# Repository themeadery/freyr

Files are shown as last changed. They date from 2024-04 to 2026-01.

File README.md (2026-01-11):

# Freyr

NOTE: This documentation is horribly out of date. There is exactly ONE user of this software: me, so updating it hasn't been a priority. I keep making major changes and not documenting.

tl;dr Yeah, but what does it look like?

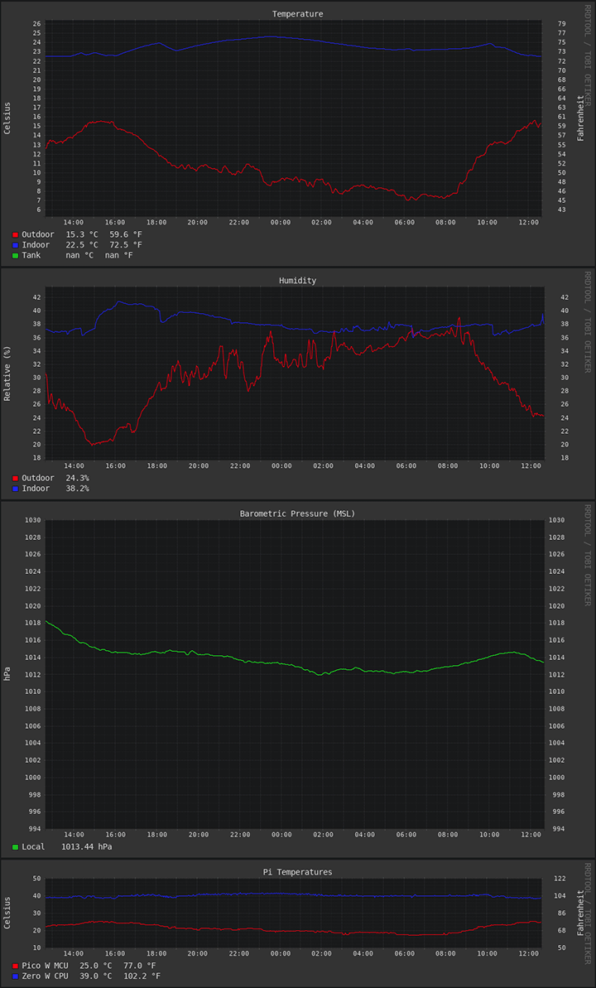
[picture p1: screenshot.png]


This started out as a project to control my reef aquarium, hence the name. It then morphed into a simple Python script to check the indoor temp/humidity and compare it with the outdoors using OpenWeather API. Update: It now monitors the temperature of my aquarium!

## Raspberry Pi

I moved the project from a FT232H to a Raspberry Pi Zero W and added a DS18B20 waterproof temperature sensor for an aquarium. With plenty of GPIO on the Pi and relays in hand, I plan on controlling pumps/lights/etc in the future.

### Hardware

#### BME680

<https://pinout.xyz/pinout/i2c>

- VCC to 3v3 (pin 1)
- GND to ground (any)
- SCL to GPIO 3 [I2C1 SCL Clock] (pin 5)
- SDA to GPIO 2 [I2C1 SDA Data] (pin 3)
- SDO to nothing
- CS to ground (any)

During testing I kept having failures of the sensor until I discovered an unofficial fix that contradicts the official documentation a bit. CS must be run to a ground pin. All of a sudden the sensor was rock solid stable for weeks after that.

#### Si7021

<https://pinout.xyz/pinout/i2c>

- VIN to 3v3 (pin 1)
- GND to ground (pin 9)
- SCL to GPIO 3 [I2C1 SCL Clock] (pin 5)
- SDA to GPIO 2 [I2C1 SDA Data] (pin 3)

This sensor always seems to work no matter what and is very accurate. I am impressed with the performance. I am currently using it outdoors on a Pico W, so the wiring is different than shown above.

#### DS18B20

<https://pinout.xyz/pinout/1_wire>

- Red Wire to 5v (pin 2)
- Blue Wire to ground (pin 6 or 9)
- Yellow Wire to GPIO 4 [Data] (pin 7)
- 4k7 pullup resistor between 5V and Data (yellow wire)

According to my testing, Google searches, and the DS18B20 datasheet 3v3 is not enough voltage to pull up the data line with the commonly included 4k7 resistor. I measured ~1.6 volts with the 4k7 resistor in place and the datasheet says it wants a minimum of 3.0 volts. I was having massive dropouts of the sensor until I switched everything from the 3v3 rail to the 5v rail. I don't know how anybody else got it working on 3v3 and then wrote the guides floating around the web (I'm looking at you too Adafruit!). You could, of course, substitute an appropriate resistor and still use 3v3 based on some multimeter measuring, calculating, etc. But why not give that sucker some juice! It's been rock solid since I changed to the 5v rail + 4k7 pullup.

### Dependencies

You can satisfy pretty much all dependencies with these commands on a fresh Pi:

```bash
sudo apt install git nginx rrdtool python3-rrdtool python3-pip
sudo pip install adafruit-circuitpython-si7021
sudo pip install git+https://github.com/nicmcd/vcgencmd.git
```

I2C and 1-Wire interfaces must be turned on in ```$ sudo raspi-config```

### RRD

#### Create RRD databases

```bash
rrdtool create temperatures.rrd --step 60 DS:outdoor:GAUGE:120:-20:55 DS:indoor:GAUGE:120:0:55 DS:tank:GAUGE:120:0:55 DS:pi:GAUGE:120:0:100 DS:picow:GAUGE:120:0:100 DS:outdoor_dew:GAUGE:120:-80:55 DS:indoor_dew:GAUGE:120:-80:55 RRA:LAST:0.5:1:2880
rrdtool create humidities.rrd --step 60 DS:outdoor:GAUGE:120:0:100 DS:indoor:GAUGE:120:0:100 RRA:LAST:0.5:1:2880
rrdtool create pressures.rrd --step 60 DS:indoor:GAUGE:120:900:1100 RRA:LAST:0.5:1:2880
rrdtool create gas.rrd --step 60 DS:indoor:GAUGE:120:50:200000 RRA:LAST:0.5:1:2880
rrdtool create uv.rrd --step 60 DS:outdoor:GAUGE:120:0:20 RRA:LAST:0.5:1:2880
rrdtool create wind.rrd --step 60 DS:outdoor_wind:GAUGE:120:0:100 DS:outdoor_windGust:GAUGE:120:0:100 RRA:LAST:0.5:1:2880
```

This will create databases with a 60 second interval, 120 second heartbeat timeout, between -20 and 55 degrees Celsius for the outdoor sensor, between 0 and 55 degrees Celsius for the indoor sensors, between -80 and 55 degrees Celsius dewpoints, 0-100 degrees Celsius for the pi CPU sensor, 0-100% relative humidity, 800-1100 hPa pressure, and 50-200,000 ohms gas resistance with 48 hours of data before rolling over. The uv database will have an 1800 second interval with a 3600 second heartbeat timeout (due to API rate limits at openuv.io) and a range between 0-20 (unitless). The wind database will have a 120 second interval with a 240 second heartbeat timeout (due again to API rate limits at OWM) and a range between 0-100 mph.

More information here: <https://michael.bouvy.net/post/graph-data-rrdtool-sensors-arduino>

### HTML

```index.html```

Very simple HTML to display the graphs. You will likely want a webserver for this. I use nginx. It refreshes the page every 30 seconds in an attempt to reduce misses while the graphs are being generated. This doesn't work very well, so I would love to implement a server-side generated trigger for refresh, more like a "push" based system. Unfortunately, when I first looked into implementing this it looked way too complicated for my motivation at the time. Looking for better solutions.

### Relay

There are 3 python files to control a relay on the Pi GPIO pins. You can use this as a timer for lights, pumps, etc.

```relayOn.py``` Simply turns on the relay

```relayOff.py``` Simply turns off the relay

```relay.py``` Toggles the relay based on a schedule

I used ```relay.py``` for a while, but there's no need to have a constantly running python daemon just to flip a GPIO pin twice a day. I switched to a crontab schedule using the first two mentioned python scripts.

Use the example below to turn a light on at 7:00 AM and off at 7:00 PM:

```bash
crontab -e
```

```text
# m h  dom mon dow   command
0 7 * * * python /home/pi/relayOn.py
0 19 * * * python /home/pi/relayOff.py
```

### More Advanced Relay Control

```bash
pip install flask
python relayControl.py
```

This will launch a webserver that hosts a very simple webpage with some buttons that control a relay. This depends on relayOn.py and relayOff.py, which you can edit to your liking and of course expand everything to control more relays.

### Handling Unforseen Errors

I have tried to continually improve error handling inside the main ```reefer.py``` script, however there are still errors that can pop up. I am usually running the script using ```$ python reefer.py &``` or some variation thereof to background the process and/or handle stdout/stderr logging (in addition to the built-in logging), but I am still getting various crashes which are not obvious looking at the graphs (they just stop on the last data point). So there is no way of knowing the main process crashed besides waiting a while and seeing the timestamp at the extreme right of the graphs is old.

The API's I am poking prove to be a continuous source of beard-pulling as I try to debug what is failing. I honestly did not expect polling of aviation METAR data from a government website to be so unreliable for example.

systemd to the rescue?

```bash
mkdir -p .config/systemd/user
cp reefer.service .config/systemd/user
systemctl --user start reefer
systemctl --user enable reefer
sudo loginctl enable-linger pi
```

This should automatically restart the script if it fails in any fashion and also log it properly. Note that this service is running as the unprivileged 'pi' user. The way I have my files setup in the pi home dir and nginx makes this work for my particular setup. You could do this all as root in ```/etc/systemd/system``` if you want to do it that way and manage permissions accordingly.

The ```reefer.service``` systemd unit file is very simple and included in the repo:

```text
[Unit]
Description=Reefer Service
After=network.target

[Service]
Type=simple
ExecStart=/usr/bin/python /home/pi/reefer.py
Restart=always

[Install]
WantedBy=multi-user.target
```

Note: The service file(s) have been updated to run as root like most services. No need to 'systemctl --user' anymore.

I realize this is turning more into a glorified weather station app, but that's where my interests have led me!

#### TODO

- ~~Move generated files to tmpfs as to not kill the sdcard with all the writes.~~
- Document tmpfs and symbolic link to files
- ~~Maybe switch from nginx to built-in Python webserver to further reduce system load, configuration, writes to sdcard, etc.~~
- Remove DS18B20 references and documentation
- Add BME680 documentation
- ~~Add Pi Pico W + Si7021 sattelite sensor code~~ and documentation
- ~~Squash indoor/outdoor pressures to "local"~~
- ~~Output data to Wunderground~~
- ~~Break out more things in main loop to functions and use main loop for flow control only (aka refactoring?)~~
- ~~Add High/Low stats~~
- ~~Log rotation using logging.handlers.RotatingFileHandler~~
- ~~Break out graphing args to variables, squash common args to reusable variable~~
- ~~Switch to built in Python module~~
- ~~Break secrets out to external file (lat, lon, API key, etc)~~
- ~~Fix readings from barometer and gas resistance sensor on first loop iteration~~
- ~~Rename project to Freyr~~

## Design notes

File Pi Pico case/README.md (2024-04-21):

"Case_Lower_No_Vent.stl" needs to be scaled to 10% to be the correct size

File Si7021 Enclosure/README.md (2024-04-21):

flip the Top part over 180° before printing

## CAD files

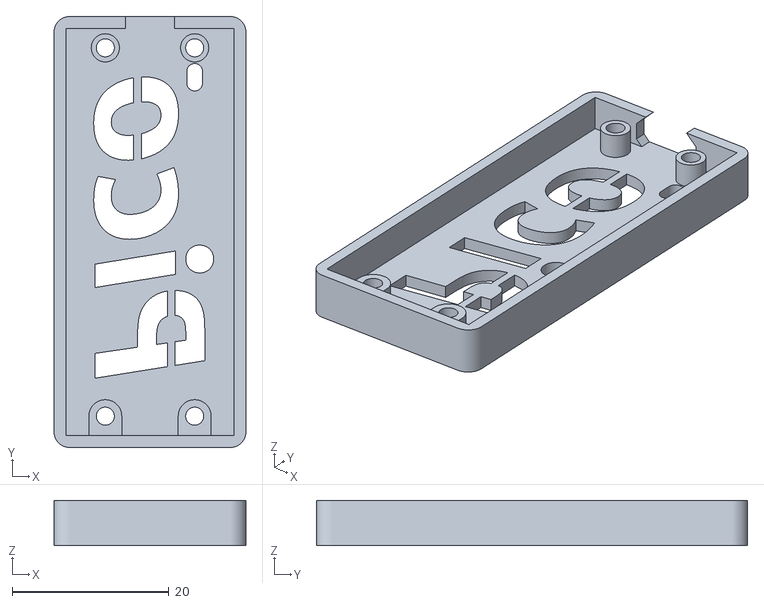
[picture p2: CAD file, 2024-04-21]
Pi Pico case/Case_Upper.STL
24.5 x 55.0 x 5.80

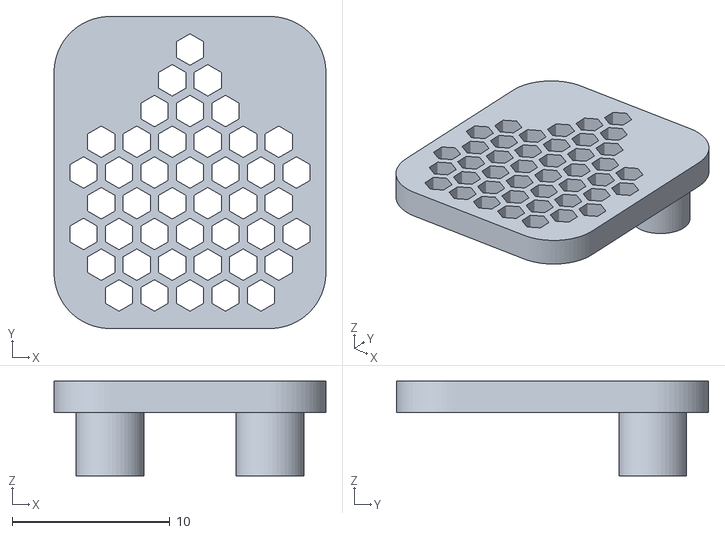
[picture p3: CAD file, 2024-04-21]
Si7021 Enclosure/Top.stl
17.2 x 19.8 x 6.00

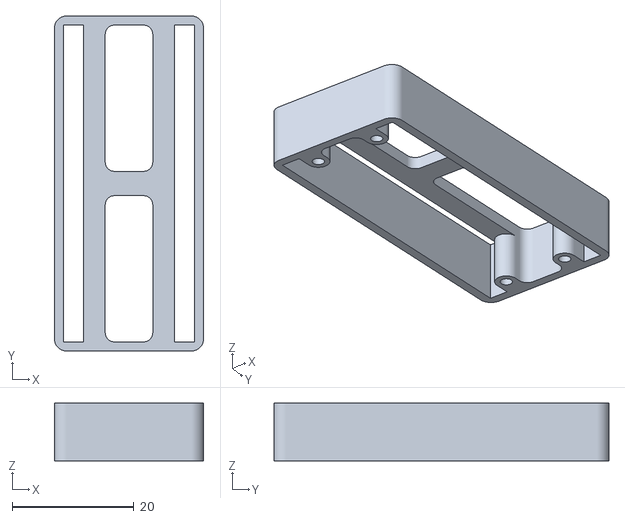
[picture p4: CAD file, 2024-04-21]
Pi Pico case/Case_Lower.STL
24.5 x 55.0 x 9.50

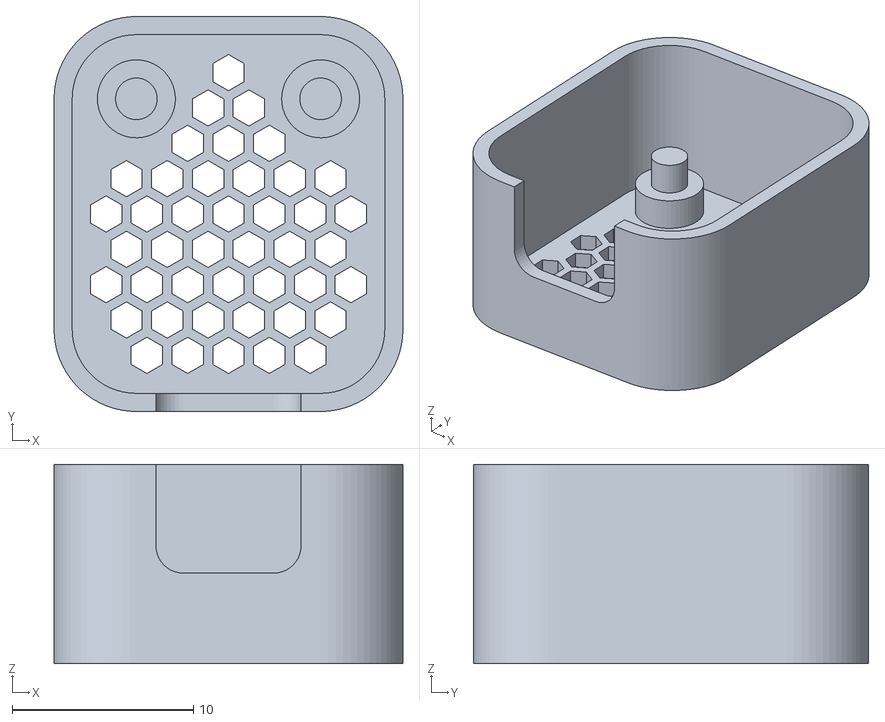
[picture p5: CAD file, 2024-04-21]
Si7021 Enclosure/Bottom.stl
19.2 x 21.8 x 11.0

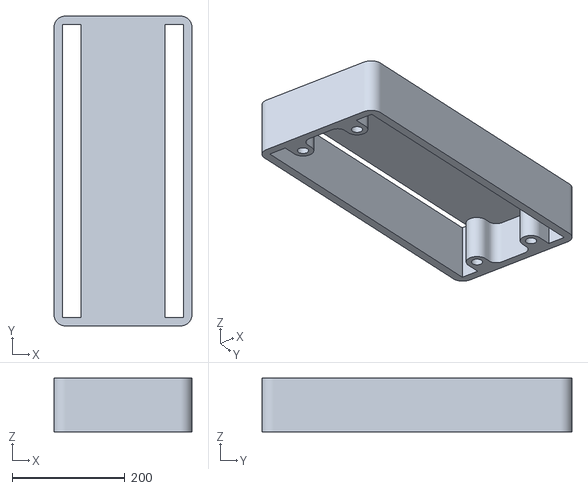
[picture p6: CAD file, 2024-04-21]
Pi Pico case/Case_Lower_No_Vent.stl
245.0 x 550.0 x 95.0

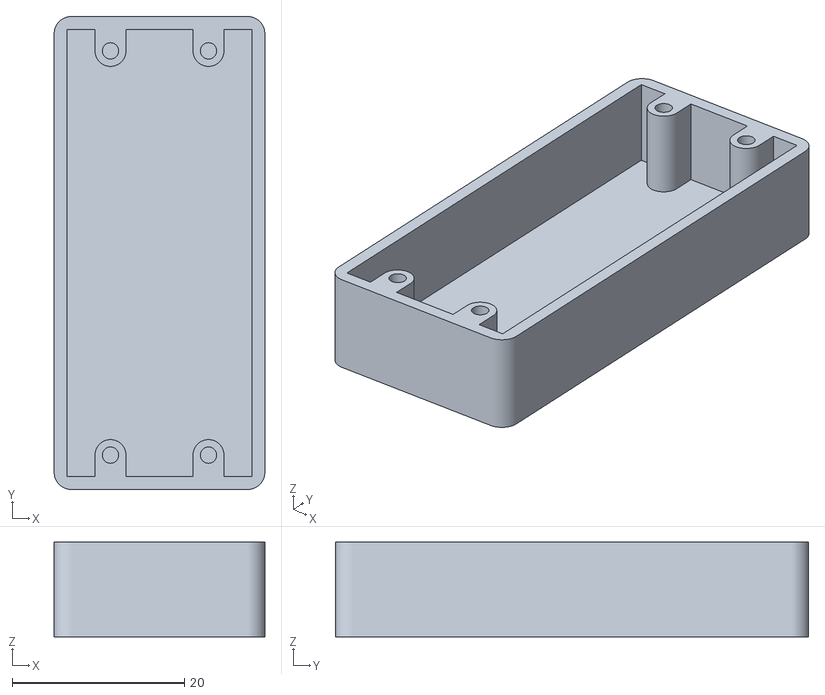
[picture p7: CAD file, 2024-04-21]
Pi Pico case/Case_Lower_Closed.STL
24.5 x 55.0 x 11.0

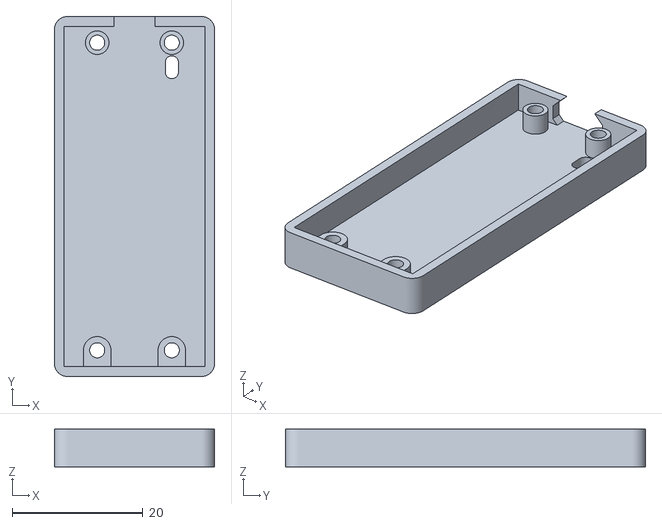
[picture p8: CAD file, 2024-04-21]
Pi Pico case/Case_Upper_No_Text.STL
24.5 x 55.0 x 5.80

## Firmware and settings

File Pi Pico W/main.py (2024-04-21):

import time
from machine import Pin, I2C, ADC
from SI7021 import SI7021
from microdot import Microdot
import gc

debug = False # set to True to turn on debugging info below

# Initialize si7021 sensor
i2c = I2C(0, sda=Pin(0), scl=Pin(1))  # i2c0 pins for Pico
si = SI7021(i2c)

# Initialize internal mcu temperature sensor
sensor = ADC(4) # ADC Pin 4

app = Microdot()

def read_mcu_temp():
    adc_value = sensor.read_u16()
    volt = (3.3/65535) * adc_value
    mcu_temp = 27 - (volt - 0.706)/0.001721
    return (mcu_temp)

@app.before_request
async def start_timer(request):
    request.g.start_time = time.ticks_ms()
    print('~~~~~~~~~~~~~~~~~~~~~~~~~~~~~~~')

@app.after_request
async def end_timer(request, response):
    duration = time.ticks_diff(time.ticks_ms(), request.g.start_time)
    if debug:
        print(f'Request took {duration} ms')
        print(f'gc.mem_alloc(): {gc.mem_alloc()}')
        print(f'gc.mem_free(): {gc.mem_free()}')
        print('Taking out the garbage...')
    gc.collect()
    if debug:
        print(f'gc.mem_alloc(): {gc.mem_alloc()}')
        print(f'gc.mem_free(): {gc.mem_free()}')

@app.get('/')
async def index(request):
    humidity = si.humidity()
    temperature = si.temperature(new=False)
    mcu_temp = read_mcu_temp()
    if debug:
        print(f'Temperature: {temperature} °C')
        print(f'Humidity: {humidity} %')
        print(f'MCU Temperature: {mcu_temp} °C')
    return {'temperature': temperature,
            'humidity': humidity, 'mcu': mcu_temp}

app.run(port=80, debug=True)

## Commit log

2023-06-05 relay.py
    Turn relay on on a schedule using GPIO
2023-06-08 Barometric Pressure, Logging
    Added barometric pressure graph
    Changed print statements to logging
2023-06-16 relay + relay docs
2023-06-26 Added relayControl feature
2023-11-07 bme680 branch initial commit
    New development branch for bme680 sensor. Adds barometric pressure readings and improves accuracy.
2023-11-07 fixed bme680 function bug
    sensor data was staying the same because sensor.get_sensor_data() function was never being called to update the data
2023-12-06 cosmetic update
    Pressure graph is insanely tall in order to deal with rrdtool quirks in parsing data. Re-centered graph based on a ~1014 hPa median average of corrected pressure by cutting off 4 hPa on the bottom. Then reduced height of graph by 5 px. Graph could be further shrunk due to the apparent nice behavior when pressure exceeds the manual bounds, which could prove handy after I plan to add a wind graph and get it all to fit on a 1080p monitor in vertical orientation.
2024-01-01 Pi Pico W + Si7021 satellite code
    rough upload of code that makes the satellite sensor work
2024-01-01 Update boot.py
    Lights up onboard LED when wlan is connected.
2024-01-03 3d printable cases
    Si7021 enclosure designed by me
    Pi Pico/Pico W case not designed by me
    [Bottom.stl, PicoBottomWithCableGap.stl, PicoTopWithCableGap.stl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]
2024-01-04 Microdot debugging
    Add debugging code to try to catch error when running a long time and print more info to the webrepl.
    [main.py]
2024-01-04 better graphs
    shrink axis fonts and reduce x-axis label complexity
    also added a timeout to the satellite API call
2024-01-04 faster boot.py script
    I don't even know how the old version worked because the LED section was wrong. Should loop until connected and connect faster than horrible old version.
2024-01-05 debug code
    Added debug code to Pico W main.py. Diagnosing a possible memory leak. Won't know what the problem is for days, but this debug code works great. There was what looked like a leak until I added the gc.collect() function. Haven't had a stable 24 hours, yet, but this will take days to diagnose.
    [main.py]
2024-01-06 New si7021 driver
    Updated si7021 driver to what I feel is a better written driver. Performance improved by 5 ms on a full loop of main.py. I like that I can get a temp reading by re-using the temp reading during the humidity reading instead of polling the sensor again. Error handling seems better written. T+7 hours in testing without fault, will commit again if a failure occurs. Better repl logging, removed old debug code.
    [main.py]
2024-01-07 better error handling
    RRD databases should be updated with NaN (which is 'U' in RRD land) if there is no data from the sensor because of errors or whatnot.
2024-01-07 Squash Pressures database
    Initial attempt to squash pressures database down to one data source, since that is all that is required.
2024-01-08 Add Pico W MCU temp
    Add Pi Pico W MCU temp to graphs. If you are doing this in the middle of a working setup you will need to run something like 'rrdtool tune temperatures.rrd DS:picow:GAUGE:120:0:100' after backing up 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
2024-01-17 Add Gas Resistance
    Big update. Turned on the gas resistance function of the BME680, created a new RRD and started graphing it. That portion of the BME680 needs lots of burn in time to stabilize. This is not IAQ, this is just the raw resistance reading so far, not compensated for anything outside of the sensor or library reading the values. Currently the sensor has trouble outputting values for the first two cycles, but there is enough code to keep everything running until it's happy.
2024-02-09 change from MAX to LAST
    Added LAST RRA's to all RRD's. Changed all graphing functions to use the LAST CF/RRA instead of MAX. Don't know why I was using max, probably following a tutorial, and it causes issues sometimes due to the way the sensors work and how RRD consolidates. It will get an erroneous/transient high value.
2024-04-01 Update README.md
    Ran into the upper limit of my gas.rrd file because of high readings from the BME680. Either my air got cleaner all of a sudden or the sensor drifted. Either way, several sources of documentation on the "normal" range of this sensor seem too tight, so I doubled the high limit before a NaN occurs.
2024-04-01 main.py debug toggle
    Added a way to turn off all debugging messages that are printed to the WebREPL console. Might speed things up.
2024-04-03 Better Pico Case
    Better Pi Pico case STL files for 3D printing
    [Case_Lower.STL, Case_Lower_Closed.STL, Case_Lower_No_Vent.stl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]
2024-07-10 refactor
    broke out stuff in the main loop to functions so that the main loop is only doing timing, flow control, calling functions, etc
2024-07-12 added dewpoints
    Temperature graph now includes dewpoints. Cleaned up old code for tank sensor. Started adding min/max stats, not finished.
2024-07-13 switch to built-in python module
    I don't know why I was using subprocess.run for so long while a built-in
    python module existed. Need to fix verbose updatev output and check
    error handling.
2024-07-21 Debug BME680 readings on service restart
    When reefer service is restarted there is a huge spike on the pressure
    graph that looks ugly and screws up all the data. Spent a few weeks
    debugging. Turns out the sensor is not ready on the first call to read
    its data because it is not heat_stable. This new code calls the function
    to read the data twice before continuing on to the main loop where good
    data is stored in the RRD. This has made the graph way more stable on
    restarts. However, I think there is still a problem with the xff setting
    on the RRD that is guessing data to insert after/before a bunch of
    NaN's. I plan on testing this if I keep seeing spikes.
2024-10-02 Outdoor Sensor Offset
    Added an offset for my outdoor sensor as it seems to have drifted over time. Also some minor cosmetic stuff on graphs and logging improvement.
2025-05-15 Massive Update
    - Restructured folders for better organization
    - Switched from nginx to Flask
    - Archived old code and files
    - Started renaming to Freyr
2025-05-19 Inter-Process Communication (IPC) with Flask
    - 'freyr.py' notifies 'freyrFlask.py' that it is done generating images
    - 'freyrFlask.py' notifies browser client to update the images
    Instead of a dumb 30 second refresh of the entire page we are using
    Flask-SocketIO which is the coolest thing in the world. I have been
    thinking of a solution to this forever!
2025-05-20 cut spikes off pressure graph
2025-05-20 attempt #69420 to squash pressure bug
2025-05-23 wow
    I finally fixed the stupid negative spike bug (mostly in pressures).
    I've been trying to fix this for YEARS. The solution was to time-align
    the updates with the RRD steps. There is an additional check to make
    sure the time-aligned epoch is greater than the last update time (to
    squash the next bug I found).
    Tobi Oetiker should have never allow the timestamp in 'rrdtool update'
    to be "N" (as in "now"). It's too prone to errors!
2025-05-25 removed useless requests.session calls and switched to consistent naming
2025-06-05 reformat pressures graph because spikes are gone
2025-07-24 adjust for sensor drift or inaccuracy in lower range
2026-02-16 Added Pi Pico with thermistor
2026-03-21 rename dir, correction factor Moved all files from agnostic "pi" directory to "Pi Zero W", as that is what it's actually running on and matches the naming convention of the other directories. Created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
2026-06-11 better error handling when Pi Pico/tank sensor is not connected
2026-09-21 color coded gas resistance line
